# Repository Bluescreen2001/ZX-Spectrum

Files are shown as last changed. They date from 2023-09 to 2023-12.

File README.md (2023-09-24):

# ZX Spectrum addons

In this repository you find some addons which I created for the Sinclair ZX Spectrum computer

## DISCLAIMER:

This is for personal use only. You may not sell this design without contacting me.

## Description:

The Sinclair Spectrum was the first Sinclair computer which offers color. Besides that the biggest new feature comparing Sinclair's first computers ZX80 and ZX81 was the hardware video generation. The ZX80 and ZX81 have to generate the video signal by software which eats up most of the CPU time.
On the ZX Spectrum this was done by the hardware itself. So the CPU can run user programs at full speed. No Slow and Fast mode necessary.

There were several versions out there. The first one was the small "rubber keyboard" version. Very small, but only with a rubber keyboard. Then there where several versions with a keyboard with "real" buttons. 
But these were also only some real keycaps pressing on a keyboard foil. Better typing as on the rubber version, but not comparable to a keyboard with real switches.

The first addon I created was a keyboard PCB with real cherry switches. See the [SpectrumPlusKeyboard directory](SpectrumPlusKeyboard).

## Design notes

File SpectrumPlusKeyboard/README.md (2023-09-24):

# ZX Spectrum Plus Keyboard

This is a Spectrum Plus keyboard PCB with Cherry switches

## DISCLAIMER:

This is for personal use only. You may not sell this design without contacting me.

## Description:

Because my old ZX Spectrum Plus keyboard foil failed I designed a PCB as a replacement for the foil using Cherry MX or ML switches. You can fit it into the original ZX Spectrum Plus case if you like to modify the case.

## CAUTION: Using Cherry MX switches

If you want to put this into the original case there is a radical modification needed. You have to remove the complete mounting plate where all this white button stamps are fitted. Remove all keycaps and it's stamps, the saw out the mounting plate, leaving only the mounting taps for the screws. 
Then screw the PCB there and press all the keycaps onto the Cherry switches. The crosses for the keys are bit small, so you need a big amount of force to press them on. You will not be able to remove them without destroying the switches.

This variant gives the best typing result, but it is really complicated to put it into the case. So I would suggest this only for a cutsom made case, maybe recreate the Spectrum Plus from an old Spectrum PCB with a defective keyboard foil.

## Easyier: Using Cherry ML switches

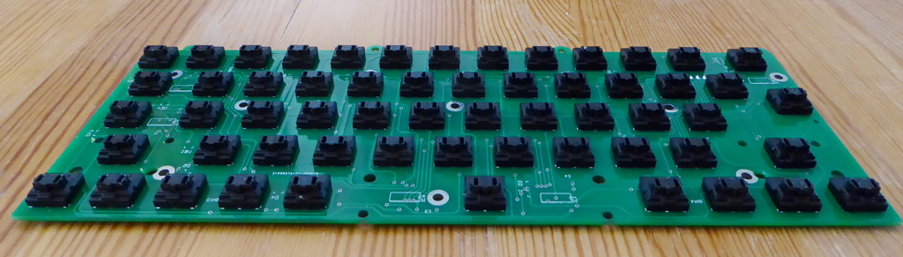
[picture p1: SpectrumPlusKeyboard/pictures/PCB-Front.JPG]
PCB-Front


These are the low profile keys. They are difficult to find. Maybe the easiest way is to buy an old Cherry low profile keyboard and unsolder the switches. If you want to put this into the original case, you have to file down the edges of the switches a bit, so that they fit into the round shafts 
where the white stamps of the original keyboard are located. Then mount the PCB instead of the foil. You have to use some washers to correct the height of the mounting tabs. The original keycaps will press the Cherry buttons by the white stamps of the original keyboard.
Alternatively to filing the edges of the switche, you can mill small edges into the case. I have an NC program for that include, see the TAP file. This modification is minimal and don't interfere with the use of the original keyboard foil in case you want to revert.

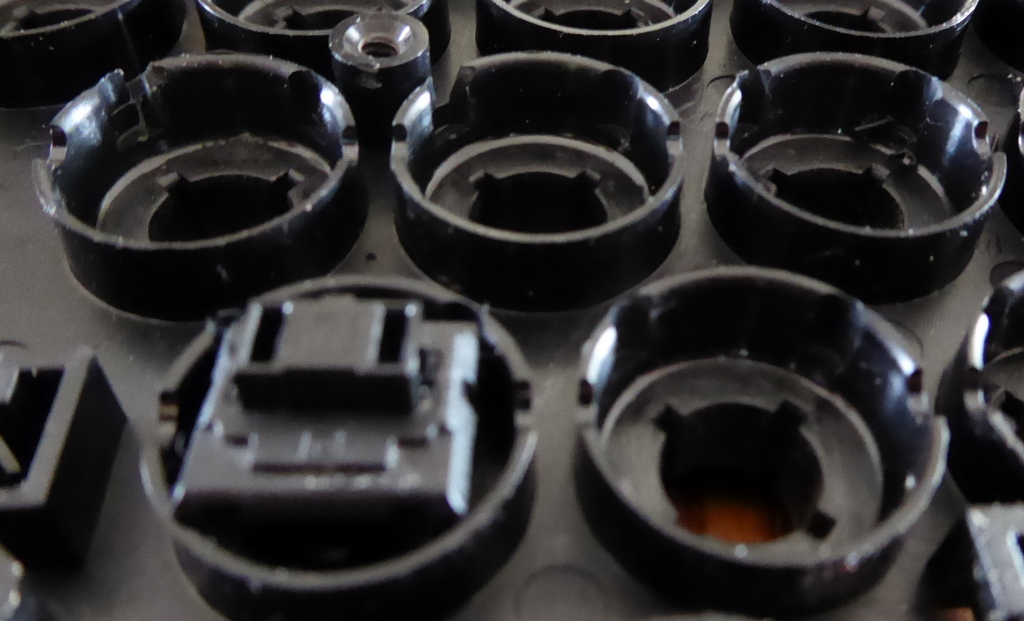
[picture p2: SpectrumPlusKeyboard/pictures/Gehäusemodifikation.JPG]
Gehäusemodifikation


## Some advice for populating the PCB

In the first PCB revision I only had the very small resistor arrays, which are difficult to solder. In the current revision I added some 0805 resistors instead. Please only mount one of the two possibilities, single resitors OR resistor arrays.

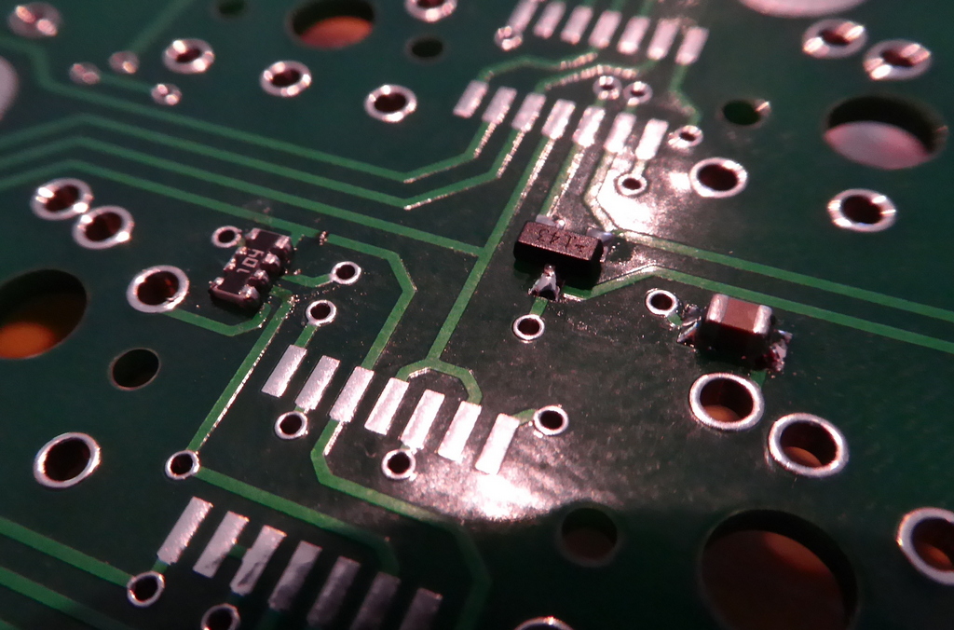
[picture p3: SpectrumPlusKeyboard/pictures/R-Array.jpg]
Resistor arrays


Beware: there are two types of diodes which are named nearly identical, but they are not the same. Be sure to order the right ones and put them in the right places!

There are two sets of solder jumpers. With these you can swap the DELETE and BREAK keys.

For placing the switches exactly, I suggest to solder only one pin at first and then move them to the right position. With the low profile keys, solder one pin per key and place the PCB onto the case and verify all keys fit into the round shafts. Only then solder the remaining pins.

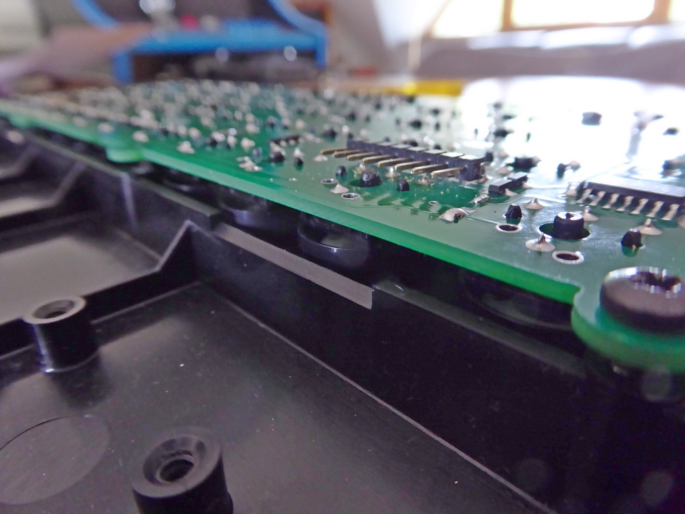
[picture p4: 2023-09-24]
SpectrumPlusKeyboard/pictures/Einbau2.JPG

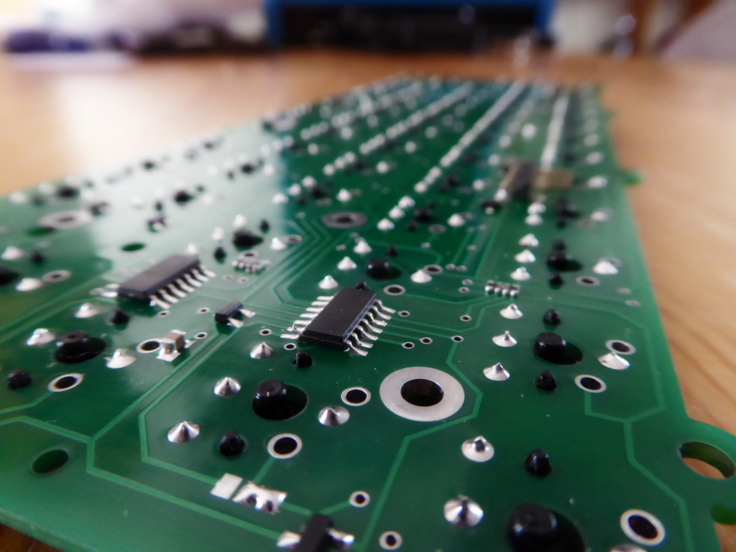
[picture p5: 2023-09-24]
SpectrumPlusKeyboard/pictures/PCB-nice.JPG

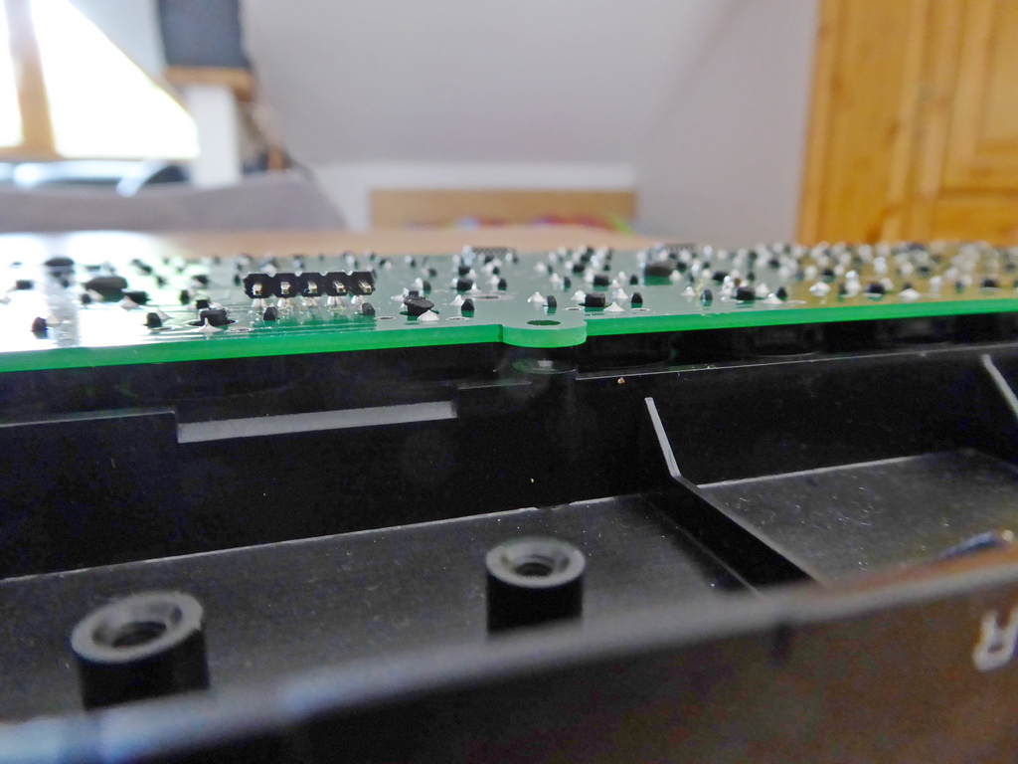
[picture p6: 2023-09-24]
SpectrumPlusKeyboard/pictures/Einbau1.JPG

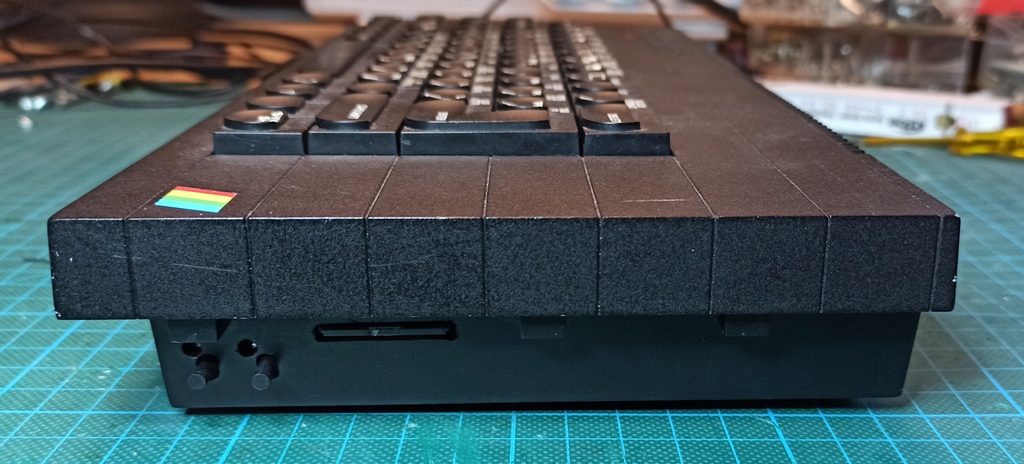
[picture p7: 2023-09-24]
SpectrumPlusKeyboard/pictures/Gehäuse_Seite.jpg

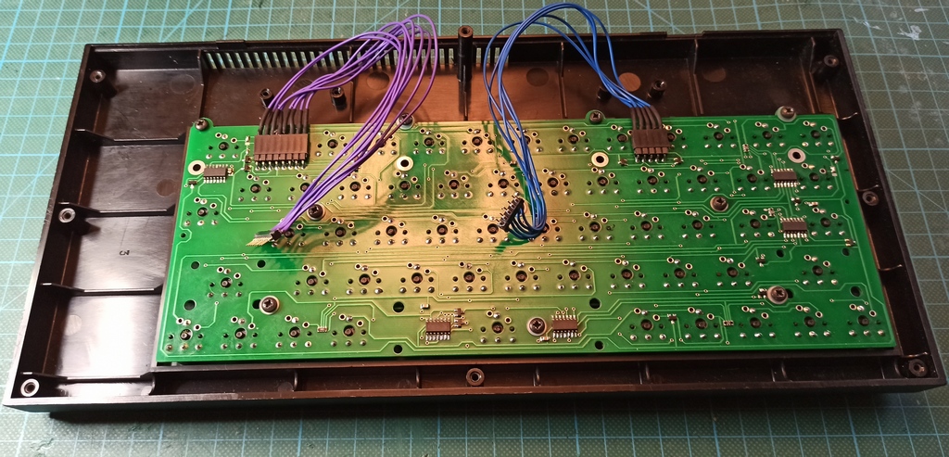
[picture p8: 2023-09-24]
SpectrumPlusKeyboard/pictures/Gehäuse_mit_Tastatur.jpg

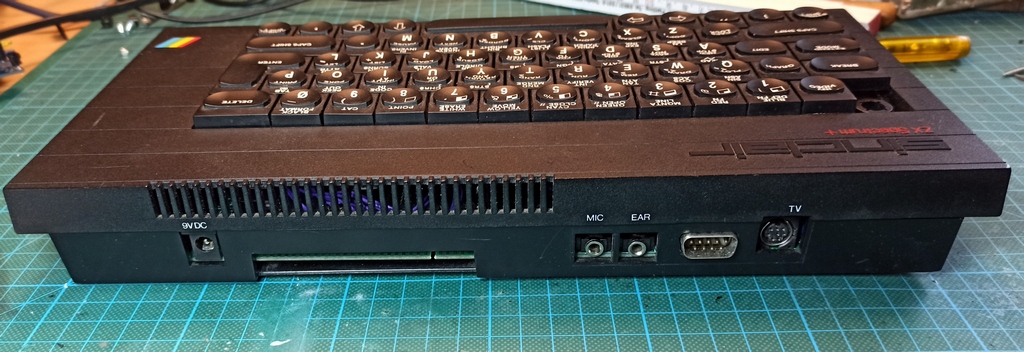
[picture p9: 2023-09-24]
SpectrumPlusKeyboard/pictures/Gehäuse hinten.jpg

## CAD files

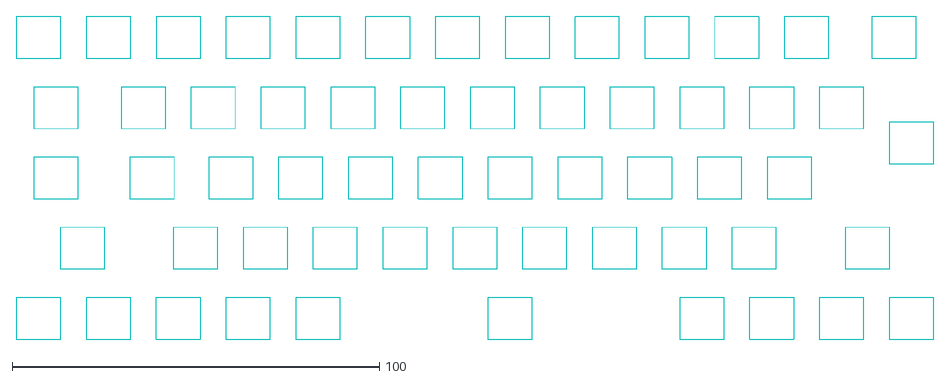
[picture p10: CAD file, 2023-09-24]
SpectrumPlusKeyboard/SpectrumPlusKeyboard_Kombi.dxf
249.6 x 87.9

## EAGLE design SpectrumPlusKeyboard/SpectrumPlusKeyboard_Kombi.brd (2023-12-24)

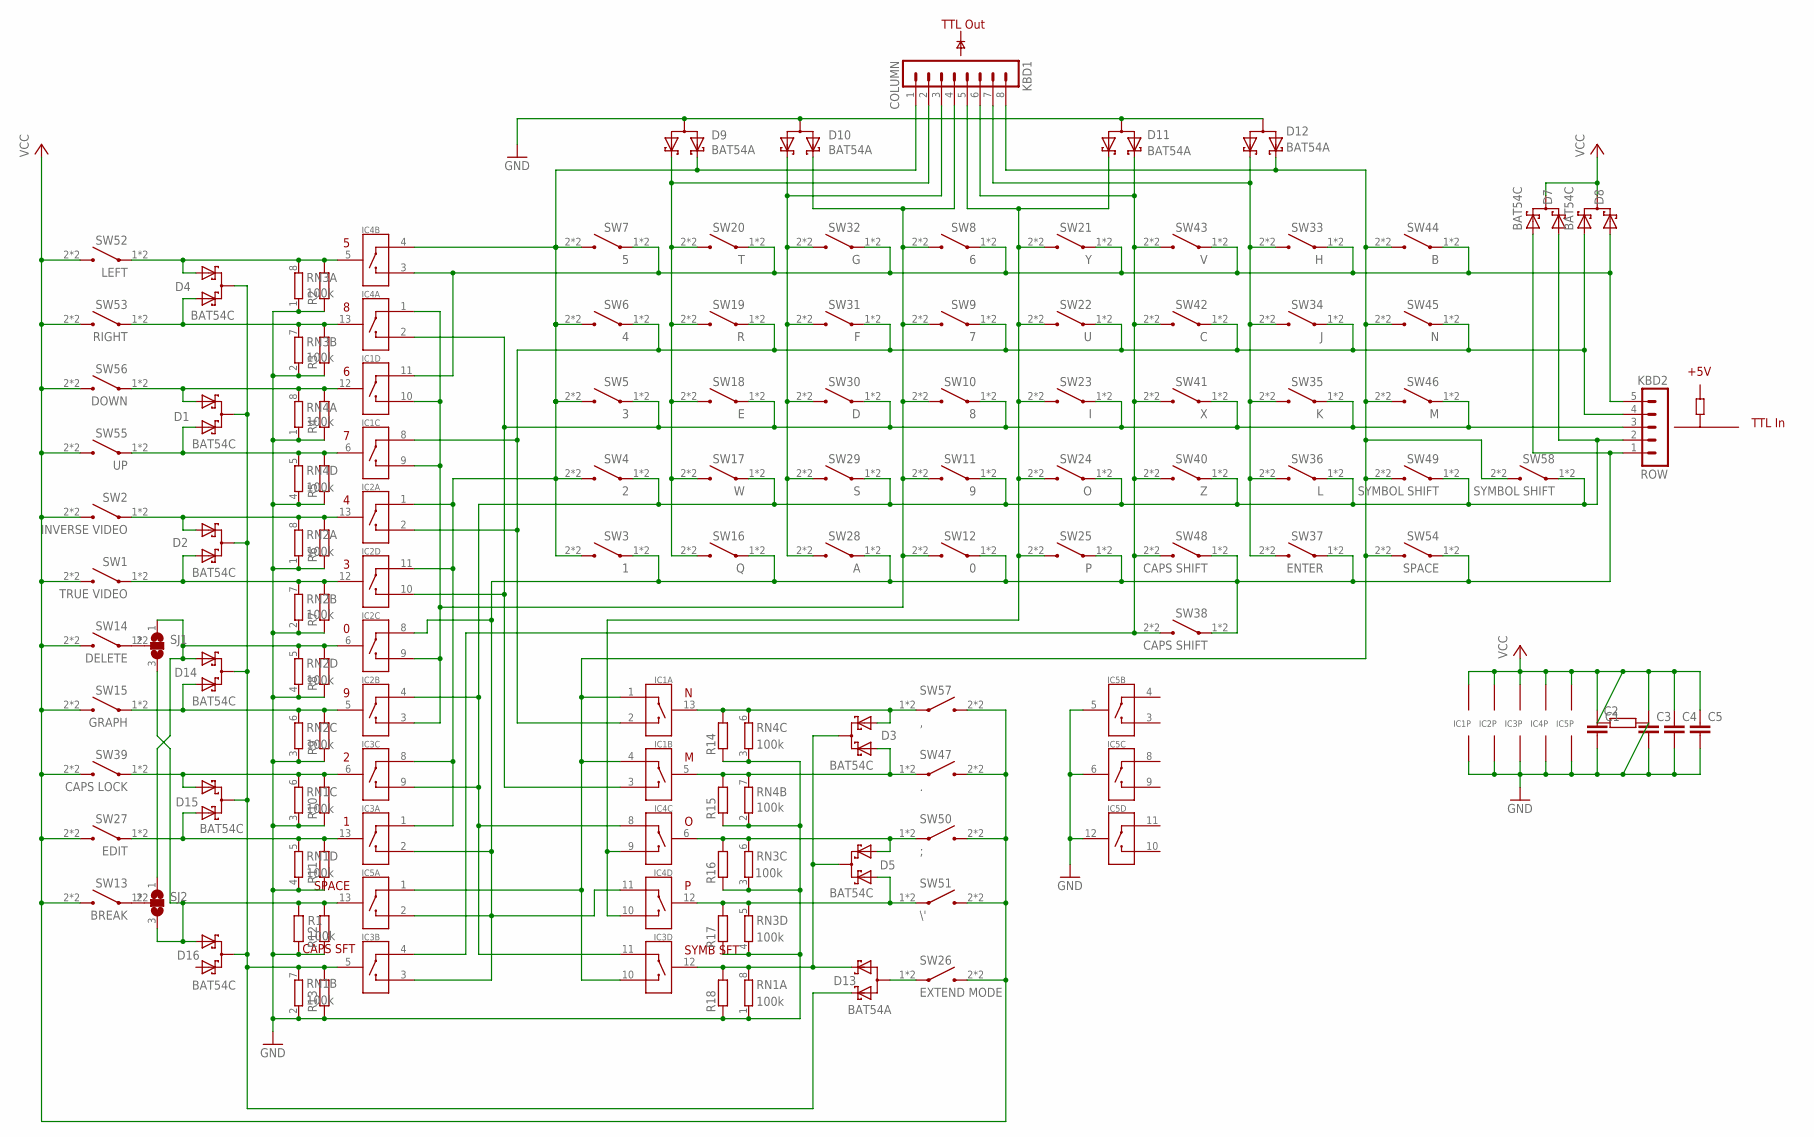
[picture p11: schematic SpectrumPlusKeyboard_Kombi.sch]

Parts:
C1, C3, C4, C5: C-EUC0805; C0805
C2: R-EU_R0805; R0805
D1, D2, D3, D4, D5, D7, D8, D14, D15, D16: BAT54C; SOT-23
D9, D10, D11, D12, D13: BAT54A; SOT-23
IC1, IC2, IC3, IC4, IC5: 4066; SO14
KBD1: COLUMN; MA08-1
KBD2: ROW; MA05-1
R1: 100k; R0805
R2, R3, R4, R5, R6, R7, R8, R9, R10, R11, R12, R13, R14, R15, R16, R17, R18: R-EU_R0805; R0805
RN1, RN2, RN3, RN4: 100k; 0603-ARC
SJ1, SJ2: SJ2W; SJ_2
SW1: TRUE VIDEO; ZX_1U_KOMBI
SW2: INVERSE VIDEO; ZX_1U_KOMBI
SW3: 1; ZX_1U_KOMBI
SW4: 2; ZX_1U_KOMBI
SW5: 3; ZX_1U_KOMBI
SW6: 4; ZX_1U_KOMBI
SW7: 5; ZX_1U_KOMBI
SW8: 6; ZX_1U_KOMBI
SW9: 7; ZX_1U_KOMBI
SW10: 8; ZX_1U_KOMBI
SW11: 9; ZX_1U_KOMBI
SW12: 0; ZX_1U_KOMBI
SW13: BREAK; ZX_1.5_KOMBI
SW14: DELETE; ZX_1.5_KOMBI
SW15: GRAPH; ZX_1U_KOMBI
SW16: Q; ZX_1U_KOMBI
SW17: W; ZX_1U_KOMBI
SW18: E; ZX_1U_KOMBI
SW19: R; ZX_1U_KOMBI
SW20: T; ZX_1U_KOMBI
SW21: Y; ZX_1U_KOMBI
SW22: U; ZX_1U_KOMBI
SW23: I; ZX_1U_KOMBI
SW24: O; ZX_1U_KOMBI
SW25: P; ZX_1U_KOMBI
SW26: EXTEND MODE; ZX_1.5_KOMBI
SW27: EDIT; ZX_1.25U_KOMBI
SW28: A; ZX_1U_KOMBI
SW29: S; ZX_1U_KOMBI
SW30: D; ZX_1U_KOMBI
SW31: F; ZX_1U_KOMBI
SW32: G; ZX_1U_KOMBI
SW33: H; ZX_1U_KOMBI
SW34: J; ZX_1U_KOMBI
SW35: K; ZX_1U_KOMBI
SW36: L; ZX_1U_KOMBI
SW37: ENTER; ZX_ENTER_KOMBI
SW38, SW48: CAPS SHIFT; ZX_2.3U_KOMBI
SW39: CAPS LOCK; ZX_1U_KOMBI
SW40: Z; ZX_1U_KOMBI
SW41: X; ZX_1U_KOMBI
SW42: C; ZX_1U_KOMBI
SW43: V; ZX_1U_KOMBI
SW44: B; ZX_1U_KOMBI
SW45: N; ZX_1U_KOMBI
SW46: M; ZX_1U_KOMBI
SW47: .; ZX_1U_KOMBI
SW49, SW58: SYMBOL SHIFT; ZX_1U_KOMBI
SW50: ;; ZX_1U_KOMBI
SW51: \'; ZX_1U_KOMBI
SW52: LEFT; ZX_1U_KOMBI
SW53: RIGHT; ZX_1U_KOMBI
SW54: SPACE; ZX_SPACE_KOMBI
SW55: UP; ZX_1U_KOMBI
SW56: DOWN; ZX_1U_KOMBI
SW57: ,; ZX_1U_KOMBI

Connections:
COL1: D9.1 (K1), IC2.1 (IO), IC2.11 (IO), IC3.1 (IO), IC3.8 (IO), IC4.4 (IO), KBD1.1, SW3.2, SW3.2B (2), SW4.2, SW4.2B (2), SW5.2, SW5.2B (2), SW6.2, SW6.2B (2), SW7.2, SW7.2B (2)
COL2: D9.2 (K2), KBD1.2, SW16.2, SW16.2B (2), SW17.2, SW17.2B (2), SW18.2, SW18.2B (2), SW19.2, SW19.2B (2), SW20.2, SW20.2B (2)
COL3: D10.2 (K2), KBD1.3, SW28.2, SW28.2B (2), SW29.2, SW29.2B (2), SW30.2, SW30.2B (2), SW31.2, SW31.2B (2), SW32.2, SW32.2B (2)
COL4: D10.1 (K1), IC1.9 (OI), IC1.10 (OI), IC2.3 (OI), IC2.9 (OI), IC4.1 (IO), KBD1.4, SW8.2, SW8.2B (2), SW9.2, SW9.2B (2), SW10.2, SW10.2B (2), SW11.2, SW11.2B (2), SW12.2, SW12.2B (2)
COL5: D11.1 (K1), IC4.9 (OI), IC4.10 (OI), KBD1.5, SW21.2, SW21.2B (2), SW22.2, SW22.2B (2), SW23.2, SW23.2B (2), SW24.2, SW24.2B (2), SW25.2, SW25.2B (2)
COL6: D11.2 (K2), IC3.4 (IO), KBD1.6, SW38.2, SW38.2B (2), SW40.2, SW40.2B (2), SW41.2, SW41.2B (2), SW42.2, SW42.2B (2), SW43.2, SW43.2B (2), SW48.2, SW48.2B (2)
COL7: D12.2 (K2), KBD1.7, SW33.2, SW33.2B (2), SW34.2, SW34.2B (2), SW35.2, SW35.2B (2), SW36.2, SW36.2B (2), SW37.2, SW37.2B (2)
COL8: D12.1 (K1), IC1.1 (IO), IC1.4 (IO), IC3.10 (OI), IC5.1 (IO), KBD1.8, SW44.2, SW44.2B (2), SW45.2, SW45.2B (2), SW46.2, SW46.2B (2), SW49.2, SW49.2B (2), SW54.2, SW54.2B (2), SW58.2, SW58.2B (2)
GND: C1.2, C2.2, C3.2, C4.2, C5.2, D9.3 (AA), D10.3 (AA), D11.3 (AA), D12.3 (AA), IC1.7 (GND), IC2.7 (GND), IC3.7 (GND), IC4.7 (GND), IC5.5 (C), IC5.6 (C), IC5.7 (GND), IC5.12 (C), R1.1, R2.1, R3.1, R4.1, R5.1, R6.1, R7.1, R8.1, R9.1, R10.1, R11.1, R12.1, R13.1, R14.1, R15.1, R16.1, R17.1, R18.1, RN1.1, RN1.2 (1), RN1.3 (1), RN1.4 (1), RN2.1, RN2.2 (1), RN2.3 (1), RN2.4 (1), RN3.1, RN3.2 (1), RN3.3 (1), RN3.4 (1), RN4.1, RN4.2 (1), RN4.3 (1), RN4.4 (1)
unnamed: SJ1.2, SW14.1, SW14.1B (1)
unnamed: SJ2.2, SW13.1, SW13.1B (1)
unnamed: D13.3 (AA), SW26.1, SW26.1B (1)
ROW1: D8.2 (A2), IC1.11 (IO), IC4.3 (OI), KBD2.5, SW7.1, SW7.1B (1), SW8.1, SW8.1B (1), SW20.1, SW20.1B (1), SW21.1, SW21.1B (1), SW32.1, SW32.1B (1), SW33.1, SW33.1B (1), SW43.1, SW43.1B (1), SW44.1, SW44.1B (1)
ROW2: D8.1 (A1), IC1.2 (OI), IC1.8 (IO), IC2.2 (OI), KBD2.4, SW6.1, SW6.1B (1), SW9.1, SW9.1B (1), SW19.1, SW19.1B (1), SW22.1, SW22.1B (1), SW31.1, SW31.1B (1), SW34.1, SW34.1B (1), SW42.1, SW42.1B (1), SW45.1, SW45.1B (1)
ROW3: IC1.3 (OI), IC2.10 (OI), IC4.2 (OI), KBD2.3, SW5.1, SW5.1B (1), SW10.1, SW10.1B (1), SW18.1, SW18.1B (1), SW23.1, SW23.1B (1), SW30.1, SW30.1B (1), SW35.1, SW35.1B (1), SW41.1, SW41.1B (1), SW46.1, SW46.1B (1)
ROW4: D7.2 (A2), IC2.4 (IO), IC3.9 (OI), IC3.11 (IO), IC4.8 (IO), KBD2.2, SW4.1, SW4.1B (1), SW11.1, SW11.1B (1), SW17.1, SW17.1B (1), SW24.1, SW24.1B (1), SW29.1, SW29.1B (1), SW36.1, SW36.1B (1), SW40.1, SW40.1B (1), SW49.1, SW49.1B (1), SW58.1, SW58.1B (1)
ROW5: D7.1 (A1), IC2.8 (IO), IC3.2 (OI), IC3.3 (OI), IC4.11 (IO), IC5.2 (OI), KBD2.1, SW3.1, SW3.1B (1), SW12.1, SW12.1B (1), SW16.1, SW16.1B (1), SW25.1, SW25.1B (1), SW28.1, SW28.1B (1), SW37.1, SW37.1B (1), SW38.1, SW38.1B (1), SW48.1, SW48.1B (1), SW54.1, SW54.1B (1)
SW0: D14.1 (A1), IC2.6 (C), R8.2, RN2.5 (2), SJ1.1, SJ2.1
SW1: D15.1 (A1), IC3.13 (C), R11.2, RN1.5 (2), SW27.1, SW27.1B (1)
SW2: D15.2 (A2), IC3.6 (C), R10.2, RN1.6 (2), SW39.1, SW39.1B (1)
SW3: D2.2 (A2), IC2.12 (C), R7.2, RN2.7 (2), SW1.1, SW1.1B (1)
SW4: D2.1 (A1), IC2.13 (C), R6.2, RN2.8 (2), SW2.1, SW2.1B (1)
SW5: D4.1 (A1), IC4.5 (C), R2.2, RN3.8 (2), SW52.1, SW52.1B (1)
SW6: D1.1 (A1), IC1.12 (C), R4.2, RN4.8 (2), SW56.1, SW56.1B (1)
SW7: D1.2 (A2), IC1.6 (C), R5.2, RN4.5 (2), SW55.1, SW55.1B (1)
SW8: D4.2 (A2), IC4.13 (C), R3.2, RN3.7 (2), SW53.1, SW53.1B (1)
SW9: D14.2 (A2), IC2.5 (C), R9.2, RN2.6 (2), SW15.1, SW15.1B (1)
SWCSHFT: D1.3 (CC), D2.3 (CC), D4.3 (CC), D13.2 (K2), D14.3 (CC), D15.3 (CC), D16.3 (CC), IC3.5 (C), R13.2, RN1.7 (2)
SWM: D3.2 (A2), IC1.5 (C), R15.2, RN4.7 (2), SW47.1, SW47.1B (1)
SWN: D3.1 (A1), IC1.13 (C), R14.2, RN4.6 (2), SW57.1, SW57.1B (1)
SWO: D5.2 (A2), IC4.6 (C), R16.2, RN3.6 (2), SW50.1, SW50.1B (1)
SWP: D5.1 (A1), IC4.12 (C), R17.2, RN3.5 (2), SW51.1, SW51.1B (1)
SWSPC: D16.1 (A1), IC5.13 (C), R1.2, R12.2, SJ1.3, SJ2.3
SWSSHFT: D3.3 (CC), D5.3 (CC), D13.1 (K1), IC3.12 (C), R18.2, RN1.8 (2)
VCC: C1.1, C2.1, C3.1, C4.1, C5.1, D7.3 (CC), D8.3 (CC), IC1.14 (VCC), IC2.14 (VCC), IC3.14 (VCC), IC4.14 (VCC), IC5.14 (VCC), SW1.2, SW1.2B (2), SW2.2, SW2.2B (2), SW13.2, SW13.2B (2), SW14.2, SW14.2B (2), SW15.2, SW15.2B (2), SW26.2, SW26.2B (2), SW27.2, SW27.2B (2), SW39.2, SW39.2B (2), SW47.2, SW47.2B (2), SW50.2, SW50.2B (2), SW51.2, SW51.2B (2), SW52.2, SW52.2B (2), SW53.2, SW53.2B (2), SW55.2, SW55.2B (2), SW56.2, SW56.2B (2), SW57.2, SW57.2B (2)

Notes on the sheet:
SYMB SFT
CAPS SFT
SPACE
TTL Out
TTL In
+5V

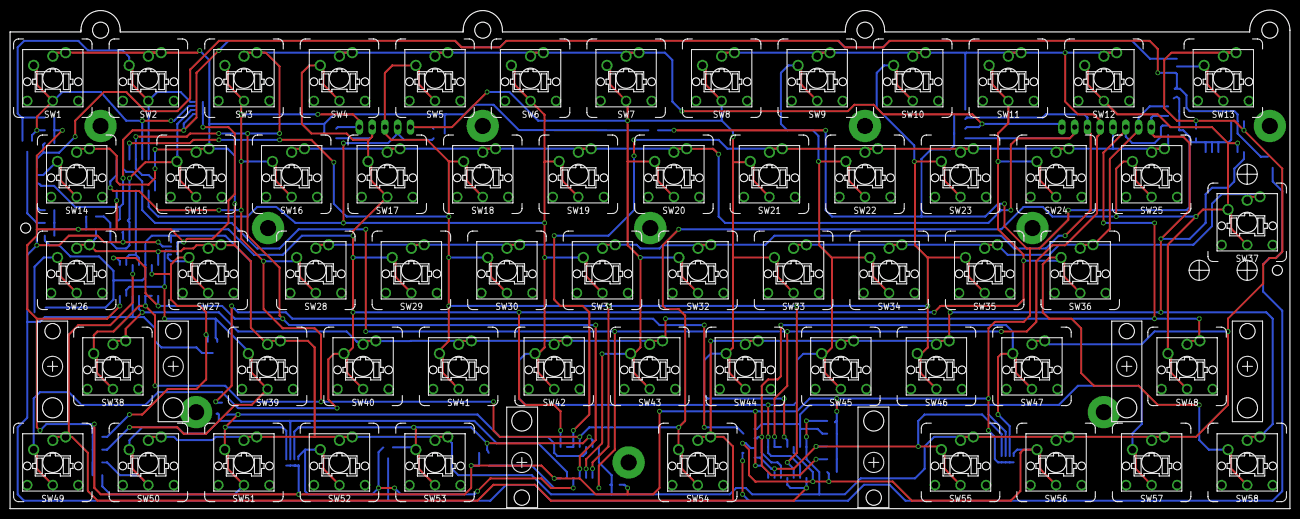
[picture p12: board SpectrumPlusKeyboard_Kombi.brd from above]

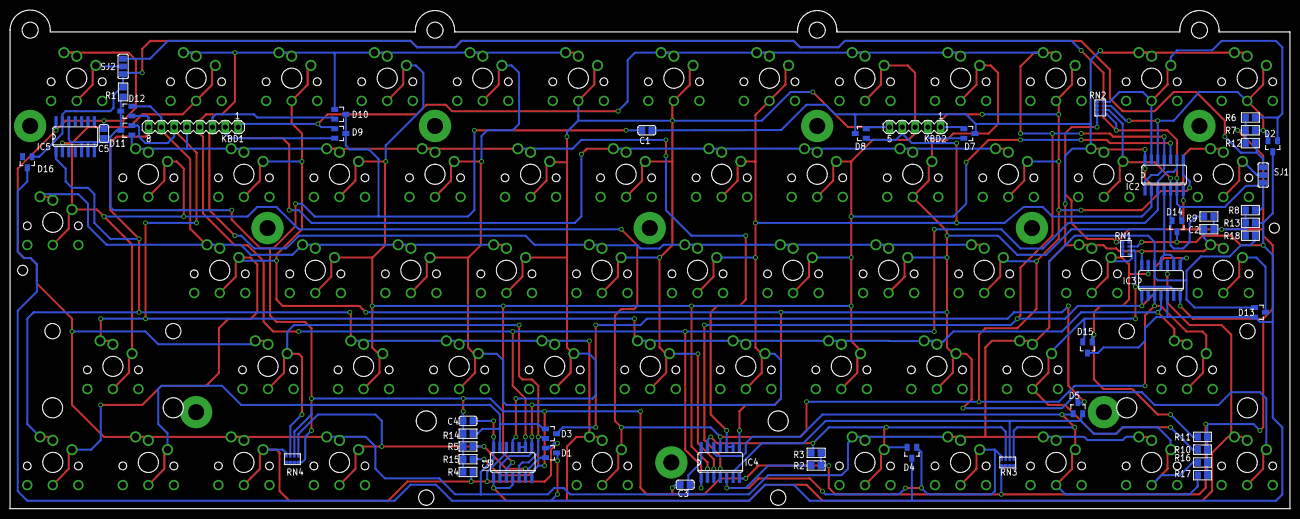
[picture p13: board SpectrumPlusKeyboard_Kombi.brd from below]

Board: 2 copper layers, 254.5 x 99.2 mm, 109 parts (51 on the bottom side), 35 nets.

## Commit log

2023-09-24 Initial upload
    This is a Spectrum Plus keyboard with Cherry switches
    [SpectrumPlusKeyboardRGB.brd, SpectrumPlusKeyboardRGB.sch, SpectrumPlusKeyboard_Kombi.brd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]
2023-12-24 Corrected Error around SW9
    [SpectrumPlusKeyboard_Kombi.brd]
